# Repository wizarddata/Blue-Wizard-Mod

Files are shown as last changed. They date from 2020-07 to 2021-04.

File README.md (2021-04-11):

# Blue Wizard Mod

This is an open source bluetooth controller for the Kinesis Advantage and Advantage 2 (see below) line of keyboards using the BlueMicro firmware.

Firmware can be found here. https://github.com/wizarddata/BlueMicro_BLE/tree/blue-wizard-working

For now, use the fork linked above to make any layout changes and utilize the adafruit nrf52832 BSP.

Gerbers and BOM are available if you'd like to build your own! If you're interested in purchasing an assembled mod email me at andrew.wells88@gmail.com or check out my etsy store. If you're so inclined, I can install a mod in your keyboard as well.
 
 https://www.etsy.com/shop/WizardKeyboards?ele=shop_open
 
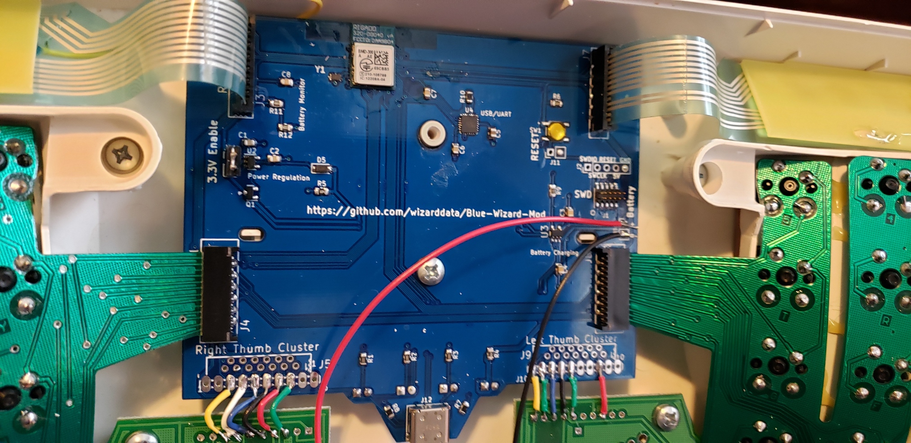
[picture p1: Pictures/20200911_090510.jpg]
Image_of_Rev0


You will need some additional hardware to make your board functional. Links are provided below for guidance:

1) Latching/Toggle/Rocker panel mount switch for power, or bridge J14 pins for always on. 

 https://www.sparkfun.com/products/11138

2) USB-C panel mount extension.
 
 https://www.amazon.com/dp/B08169ZB5C/ref=cm_sw_r_cp_api_glt_fabc_G1MT1V5PB9B76P2SWG2N?_encoding=UTF8&psc=1
 https://www.sparkfun.com/products/15455  
 
3) Momentary panel mount switch for reset (optional, reset switch is onboard).

 https://www.sparkfun.com/products/11995

4) LiPo battery.

 https://www.sparkfun.com/products/13855

***Advantage 2 Troubleshooting***  
Some keyboards experience intermittent joined activations on function keys. Installing a jumper wire from the negative battery connection to the ground pin of the 3.3v regulator can help resolve this issue. The necessary wire is pictured here:  
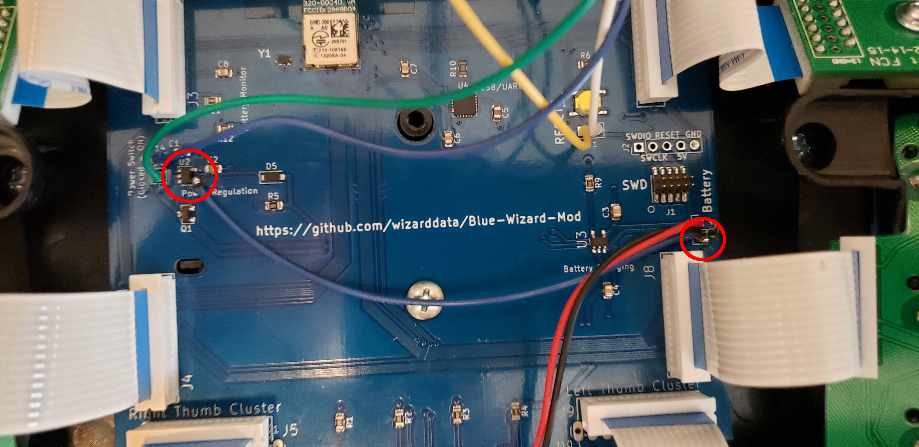
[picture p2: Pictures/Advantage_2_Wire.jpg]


Some users have reported F1 simultateously triggering F2. A 10k resistor between the pins indicated here will resolve this.  
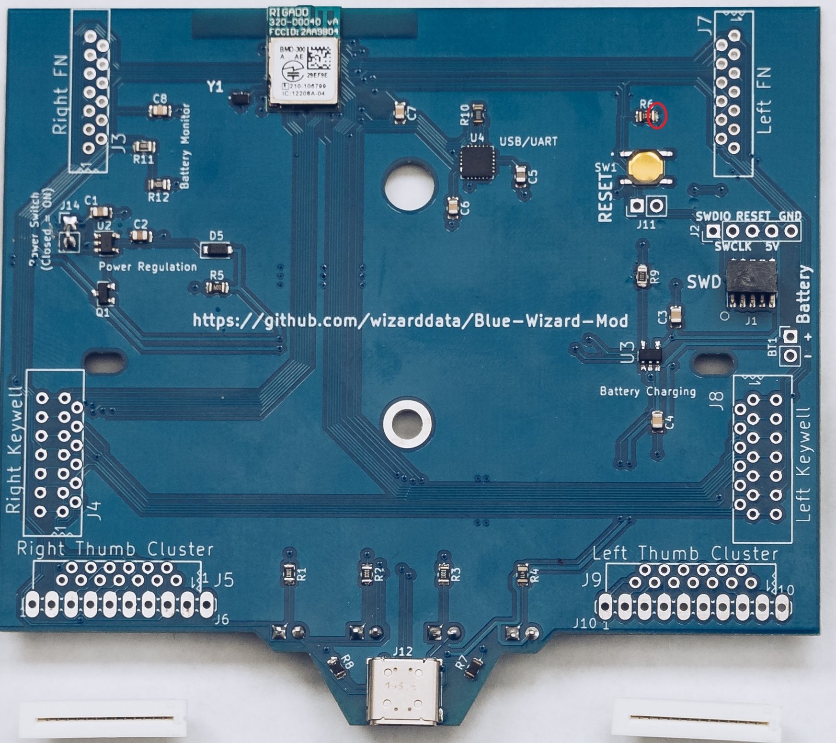
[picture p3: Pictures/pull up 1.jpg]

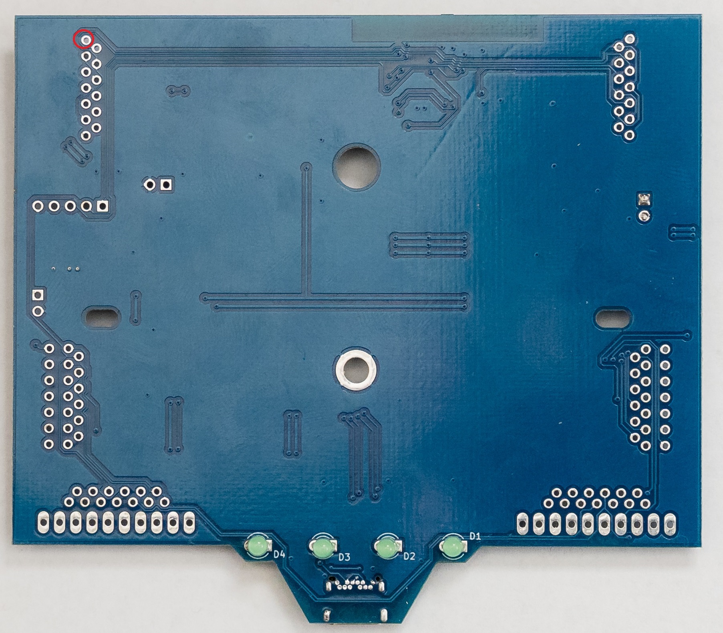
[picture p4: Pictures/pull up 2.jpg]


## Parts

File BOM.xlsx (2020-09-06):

 | Mfr. # | Description | Order Qty.
C5 | C0805C106K9PACTU | Multilayer Ceramic Capacitors MLCC - SMD/SMT 6.3volts 10uF X5R 10% | 1
C6, C7 | 885012207098 | Multilayer Ceramic Capacitors MLCC - SMD/SMT WCAP-CSGP 0.1uF 0805 10% 50V MLCC | 2
C8 | 885342207008 | Multilayer Ceramic Capacitors MLCC - SMD/SMT WCAP-CSMH 250V 1000pF 0805 10% | 1
R1, R2, R3 | CRCW08051K00FKEAC | Thick Film Resistors - SMD 1/8Watt 1Kohms 1% Commercial Use | 3
R9 | CR0805-FX-2101ELF | Thick Film Resistors - SMD 2.1K 1% | 1
R11 | CR0805-FX-8063ELF | Thick Film Resistors - SMD 806K 1% | 1
R12 | WCR0805LF2004FPLT | Thick Film Resistors - SMD 2M OHM 1% | 1
U4 | CP2104-F03-GM | I/O Controller Interface IC USB to UART Bridge QFN24 | 1
Y1 | SiT1533AI-H4-DCC-32.768E | Standard Clock Oscillators 32.768KHz R2R LVCMOS -40 to 85C 100ppm | 1
R10 | CRCW0805100RFKEA | Thick Film Resistors - SMD 1/8watt 100ohms 1% 100ppm | 1
C3, C4 | 0805X475M250CT | Multilayer Ceramic Capacitors MLCC - SMD/SMT 0805 MLCC X5R 4.7 uF +/- 20% 25 V T&R GP | 2
D5 | MBR120ESFT3G | Schottky Diodes & Rectifiers 1A 20V | 1
Q1 | BSS84 | MOSFET SOT-23 P-CH ENHANCE | 1
C1, C2 | 885012207078 | Multilayer Ceramic Capacitors MLCC - SMD/SMT WCAP-CSGP 1uF 0805 10% 25V MLCC | 2
R6 | CRCW080510K0FKEAC | Thick Film Resistors - SMD 1/8Watt 10Kohms 1% Commercial Use | 1
R5 | CRCW0805100KJNEAC | Thick Film Resistors - SMD 1/8Watt 100Kohms 5% Commercial Use | 1
R7, R8 | CRCW08055K10FKEA | Thick Film Resistors - SMD 1/8watt 5.1Kohms 1% 100ppm | 2
D1-D4 | LTL-4231N | Standard LEDs - Through Hole Green Diffused | 4
J12 | 10137062-00021LF | USB Connectors USB 3.1 RECE. CONN. Gen 1 | 1
SW1 | PTS526 SM08 SMTR2 LFS | Tactile Switches 50mA 12VDC, 5.2x5.2mm, 0.8mm H, 160gf, G leads, No ground pin, no actuator | 1
J1 | 20021121-00010C4LF | Headers & Wire Housings 1.27x1.27mm BTB, Hdr Unshrd, SMT, 10 Pos | 1
U3 | MCP73831T-2ACI/OT | Battery Management Charge mgnt contr | 1
U1 | BMD-300-A-R | Bluetooth Modules (802.15.1) Bluetooth Module Low Energy 5.0 | 1
R4 | RK73B2ATTD471J | Thick Film Resistors - SMD 1/4watts 470ohms 5% | 1
U2 | MIC5504-3.3YM5-TR | LDO Voltage Regulators Single 300mA LDO | 1
J4, J8 | 39-53-2134 | Right Angle FFC/FPC 13 POS Through Hole | 0-2 | These connectors vary depending on your advantage model.
J3, J4, J5, J7, J8, J9 | 39-53-2135 | Vertical FFC/FPC 13 POS Through Hole | 2-6

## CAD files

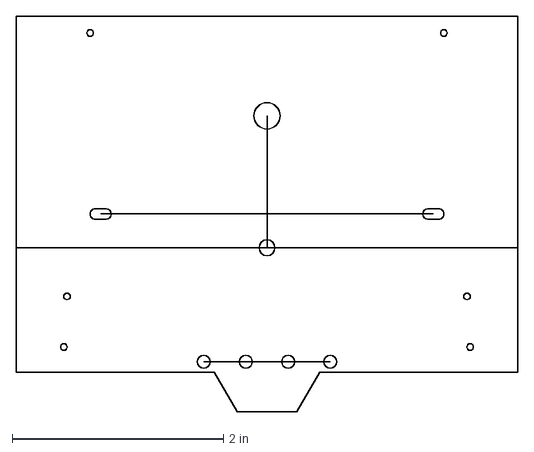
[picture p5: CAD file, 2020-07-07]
Blue Wizard PCB Footprint.dxf
4.75 x 3.75 in

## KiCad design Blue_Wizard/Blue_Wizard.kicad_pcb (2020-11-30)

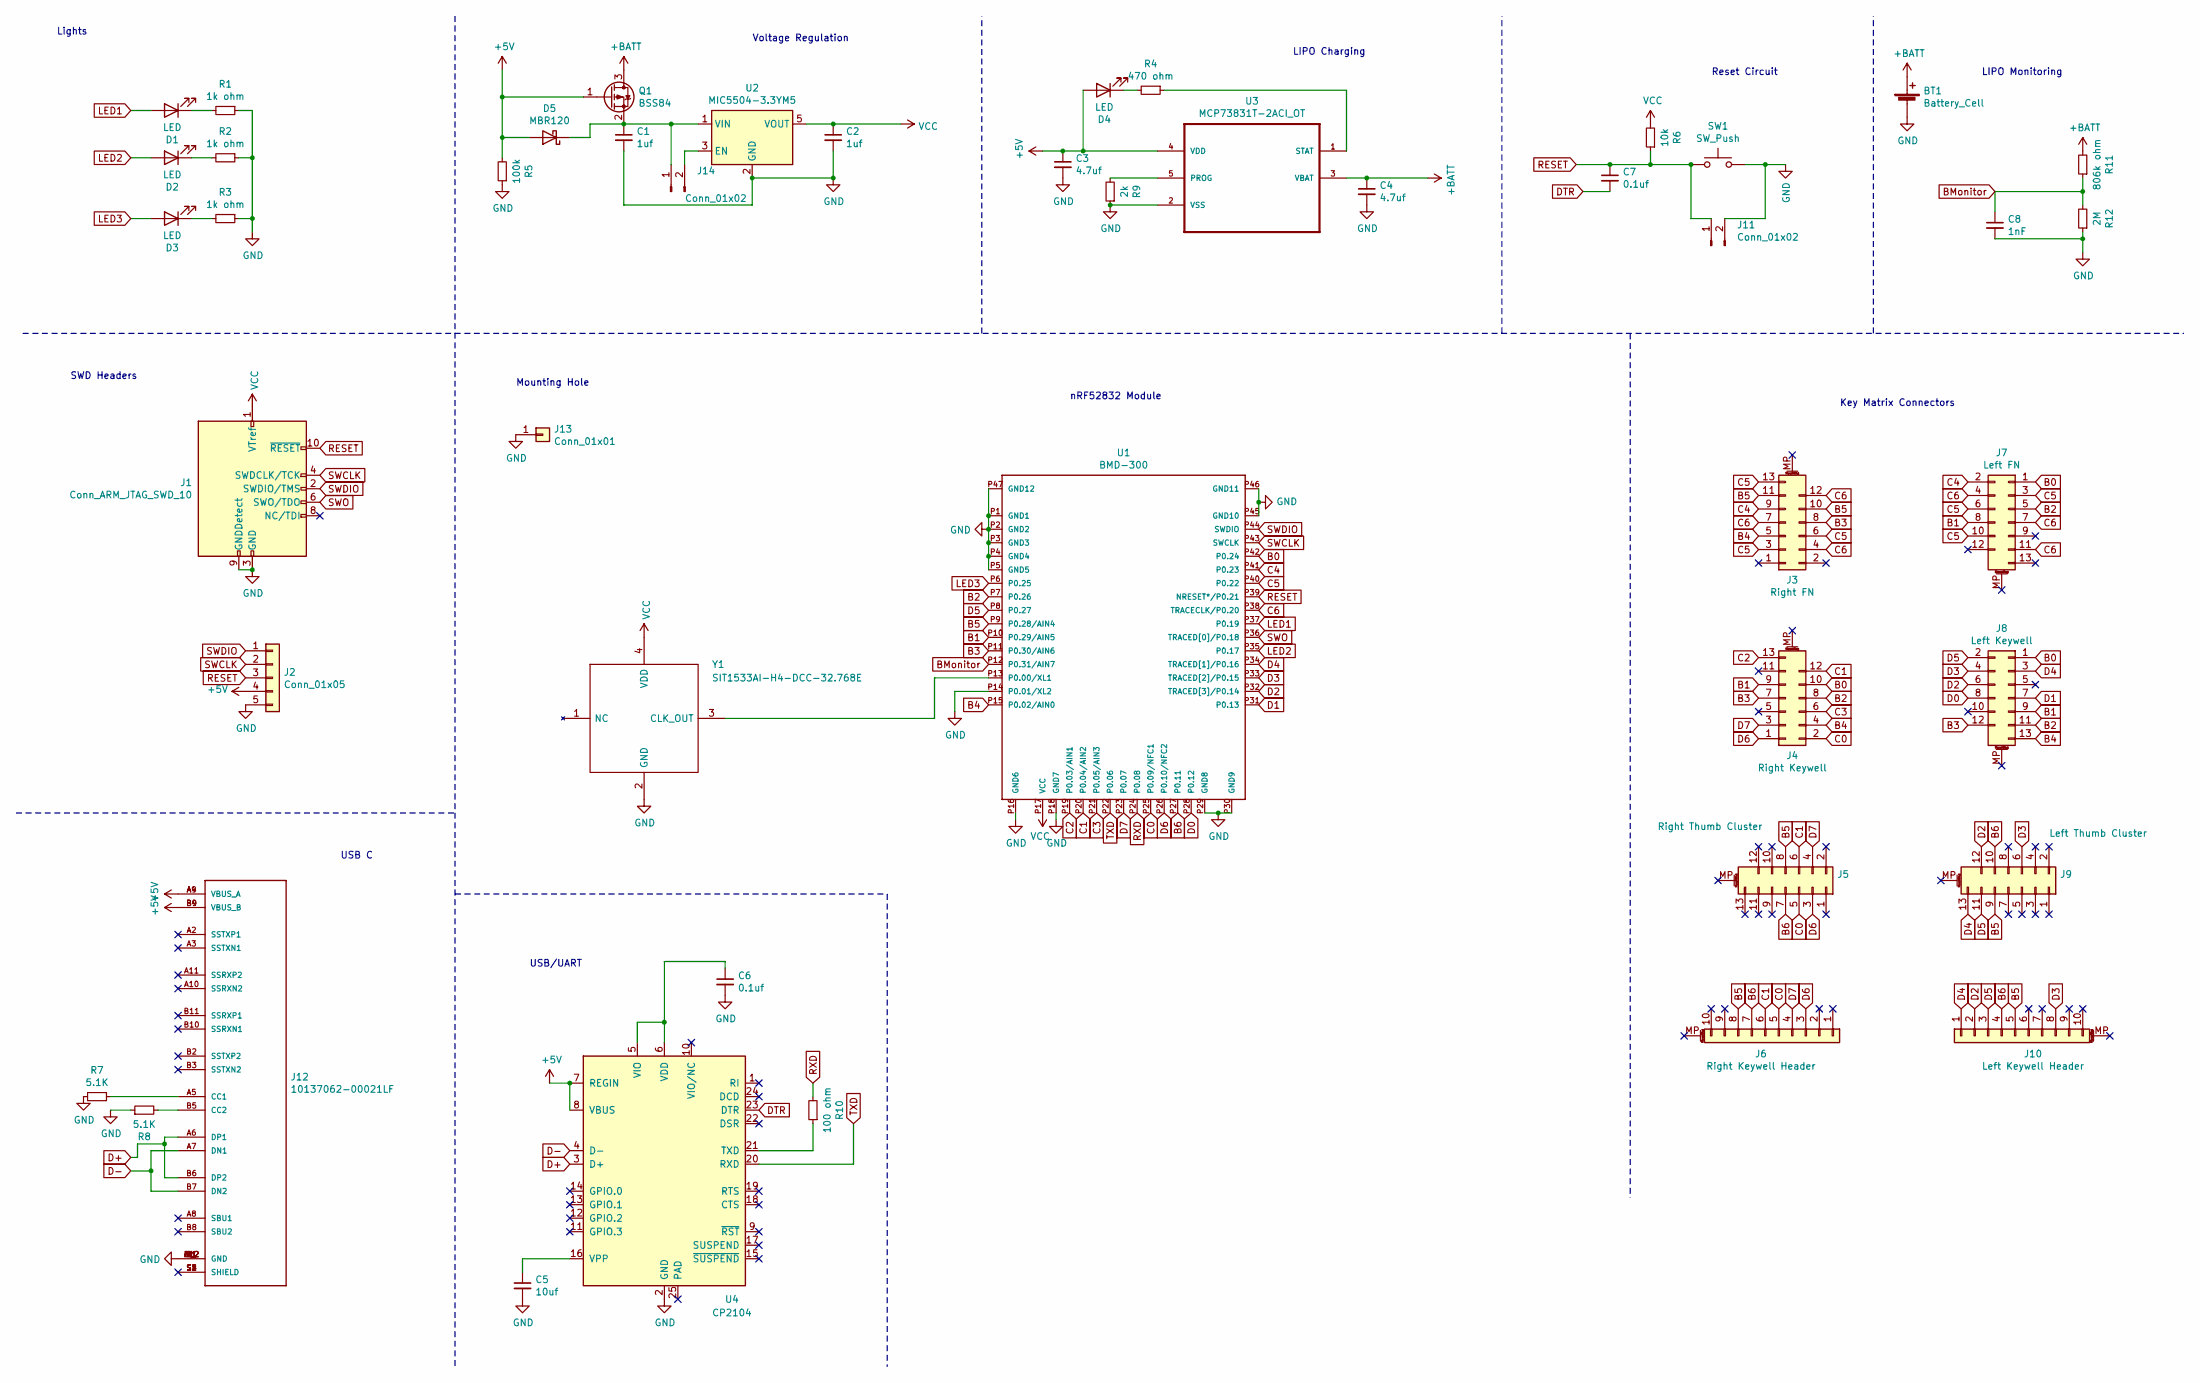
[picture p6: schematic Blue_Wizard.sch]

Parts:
BT1: Battery_Cell; PinHeader_1x02_P2.54mm_Vertical
C1, C2: 1uf; C_0805_2012Metric
C3, C4: 4.7uf; C_0805_2012Metric
C5: 10uf; C_0805_2012Metric
C6, C7: 0.1uf; C_0805_2012Metric
C8: 1nF; C_0805_2012Metric
D1, D2, D3, D4: LED; LED_D3.0mm_Clear
D5: MBR120; D_SOD-123F
J1: Conn_ARM_JTAG_SWD_10; PinHeader_2x05_P1.27mm_Vertical_SMD
J2: Conn_01x05; PinHeader_1x05_P2.54mm_Vertical
J3: Right FN; Vertical_FRC
J4: Right Keywell; Horizontal_FRC
J5: Right Thumb Cluster; Vertical_FRC
J6: Right Keywell Header; MA10-1
J7: Left FN; Vertical_FRC
J8: Left Keywell; Horizontal_FRC
J9: Left Thumb Cluster; Vertical_FRC
J10: Left Keywell Header; MA10-1
J11, J14: Conn_01x02; PinHeader_1x02_P2.54mm_Vertical
J12: 10137062-00021LF; CONN_10137062-00021LF
J13: Conn_01x01; Mounting Hole
Q1: BSS84; SOT-23
R1, R2, R3: 1k ohm; R_0805_2012Metric
R4: 470 ohm; R_0805_2012Metric
R5: 100k; R_0805_2012Metric
R6: 10k; R_0805_2012Metric
R7, R8: 5.1K; R_0805_2012Metric
R9: 2k; R_0805_2012Metric
R10: 100 ohm; R_0805_2012Metric
R11: 806k ohm; R_0805_2012Metric
R12: 2M; R_0805_2012Metric
SW1: SW_Push; SW_PTS526_SM08_SMTR2_LFS
U1: BMD-300
U2: MIC5504-3.3YM5; SOT-23-5
U3: MCP73831T-2ACI_OT; SOT95P280X145-5N
U4: CP2104; QFN-24-1EP_4x4mm_P0.5mm_EP2.6x2.6mm
Y1: SIT1533AI-H4-DCC-32.768E; SIT1533AIH4DCC32768E; Mouser Part Number 788-1533AIH4DCC32.76

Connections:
+5V: C3.1, D4.2 (A), D5.2 (A), J2.4, J12.A4 (VBUS_A), J12.A9 (VBUS_A), J12.B4 (VBUS_B), J12.B9 (VBUS_B), Q1.1 (G), R5.2, U3.4 (VDD), U4.7 (REGIN), U4.8 (VBUS)
+BATT: BT1.1 (+), C4.1, Q1.3 (D), R11.2, U3.3 (VBAT)
B0: J4.10, J7.1, J8.1, U1.P42 (P0.24)
B1: J4.9, J7.8, J8.9, U1.P10 (P0.29/AIN5)
B2: J4.8, J7.5, J8.11, U1.P7 (P0.26)
B3: J3.8, J4.7, J8.12, U1.P11 (P0.30/AIN6)
B4: J3.5, J4.4, J8.13, U1.P15 (P0.02/AIN0)
B5: J3.10, J3.11, J5.8, J6.8, J9.9, J10.5, U1.P9 (P0.28/AIN4)
B6: J5.7, J6.7, J9.10, J10.4, U1.P27 (P0.11)
BMonitor: C8.1, R11.1, R12.2, U1.P12 (P0.31/AIN7)
C0: J4.2, J5.5, J6.5, U1.P25 (P0.09/NFC1)
C1: J4.12, J5.6, J6.6, U1.P20 (P0.04/AIN2)
C2: J4.13, U1.P19 (P0.03/AIN1)
C3: J4.6, U1.P21 (P0.05/AIN3)
C4: J3.9, J7.2, U1.P41 (P0.23)
C5: J3.3, J3.6, J3.13, J7.3, J7.6, J7.10, U1.P40 (P0.22)
C6: J3.4, J3.7, J3.12, J7.4, J7.7, J7.11, U1.P38 (TRACECLK/P0.20)
D0: J8.8, U1.P28 (P0.12)
D1: J8.7, U1.P31 (P0.13)
D2: J8.6, J9.12, J10.2, U1.P32 (TRACED[3]/P0.14)
D3: J8.4, J9.6, J10.8, U1.P33 (TRACED[2]/P0.15)
D4: J8.3, J9.13, J10.1, U1.P34 (TRACED[1]/P0.16)
D5: J8.2, J9.11, J10.3, U1.P8 (P0.27)
D6: J4.1, J5.3, J6.3, U1.P26 (P0.10/NFC2)
D7: J4.3, J5.4, J6.4, U1.P23 (P0.07)
D+: J12.A6 (DP1), J12.B6 (DP2), U4.3 (D+)
D-: J12.A7 (DN1), J12.B7 (DN2), U4.4 (D-)
DTR: C7.2, U4.23 (DTR)
GND: BT1.2 (-), C1.2, C2.2, C3.2, C4.2, C5.2, C6.2, C8.2, J1.3 (GND), J1.5 (GND), J1.9 (GNDDetect), J2.5, J11.2, J12.A1 (GND), J12.A12 (GND), J12.B1 (GND), J12.B12 (GND), J13.1, R1.1, R2.1, R3.1, R5.1, R7.2, R8.1, R9.1, R12.1, SW1.2, U1.P1 (GND1), U1.P2 (GND2), U1.P3 (GND3), U1.P4 (GND4), U1.P5 (GND5), U1.P14 (P0.01/XL2), U1.P16 (GND6), U1.P18 (GND7), U1.P29 (GND8), U1.P30 (GND9), U1.P45 (GND10), U1.P46 (GND11), U1.P47 (GND12), U2.2 (GND), U3.2 (VSS), U4.2 (GND), Y1.2 (GND)
LED1: D1.2 (A), U1.P37 (P0.19)
LED2: D2.2 (A), U1.P35 (P0.17)
LED3: D3.2 (A), U1.P6 (P0.25)
unnamed: C1.1, D5.1 (K), J14.1, Q1.2 (S), U2.1 (VIN)
unnamed: C5.1, U4.16 (VPP)
unnamed: C6.1, U4.5 (VIO), U4.6 (VDD)
unnamed: D1.1 (K), R1.2
unnamed: D2.1 (K), R2.2
unnamed: D3.1 (K), R3.2
unnamed: D4.1 (K), R4.2
unnamed: J12.A5 (CC1), R7.1
unnamed: J12.B5 (CC2), R8.2
unnamed: J12.S1 (SHIELD), J12.S2 (SHIELD), J12.S3 (SHIELD), J12.S4 (SHIELD)
unnamed: J14.2, U2.3 (EN)
unnamed: R4.1, U3.1 (STAT)
unnamed: R9.2, U3.5 (PROG)
unnamed: R10.1, U4.21 (TXD)
unnamed: U1.P13 (P0.00/XL1), Y1.3 (CLK_OUT)
RESET: C7.1, J1.10 (~RESET~), J2.3, J11.1, R6.1, SW1.1, U1.P39 (NRESET*/P0.21)
RXD: R10.2, U1.P24 (P0.08)
SWCLK: J1.4 (SWDCLK/TCK), J2.2, U1.P43 (SWCLK)
SWDIO: J1.2 (SWDIO/TMS), J2.1, U1.P44 (SWDIO)
SWO: J1.6 (SWO/TDO), U1.P36 (TRACED[0]/P0.18)
TXD: U1.P22 (P0.06), U4.20 (RXD)
VCC: C2.1, J1.1 (VTref), R6.2, U1.P17 (VCC), U2.5 (VOUT), Y1.4 (VDD)

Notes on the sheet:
SWD Headers
Lights
Voltage Regulation
LIPO Charging
Reset Circuit
LIPO Monitoring
Key Matrix Connectors
Mounting Hole
USB/UART
USB C
nRF52832 Module

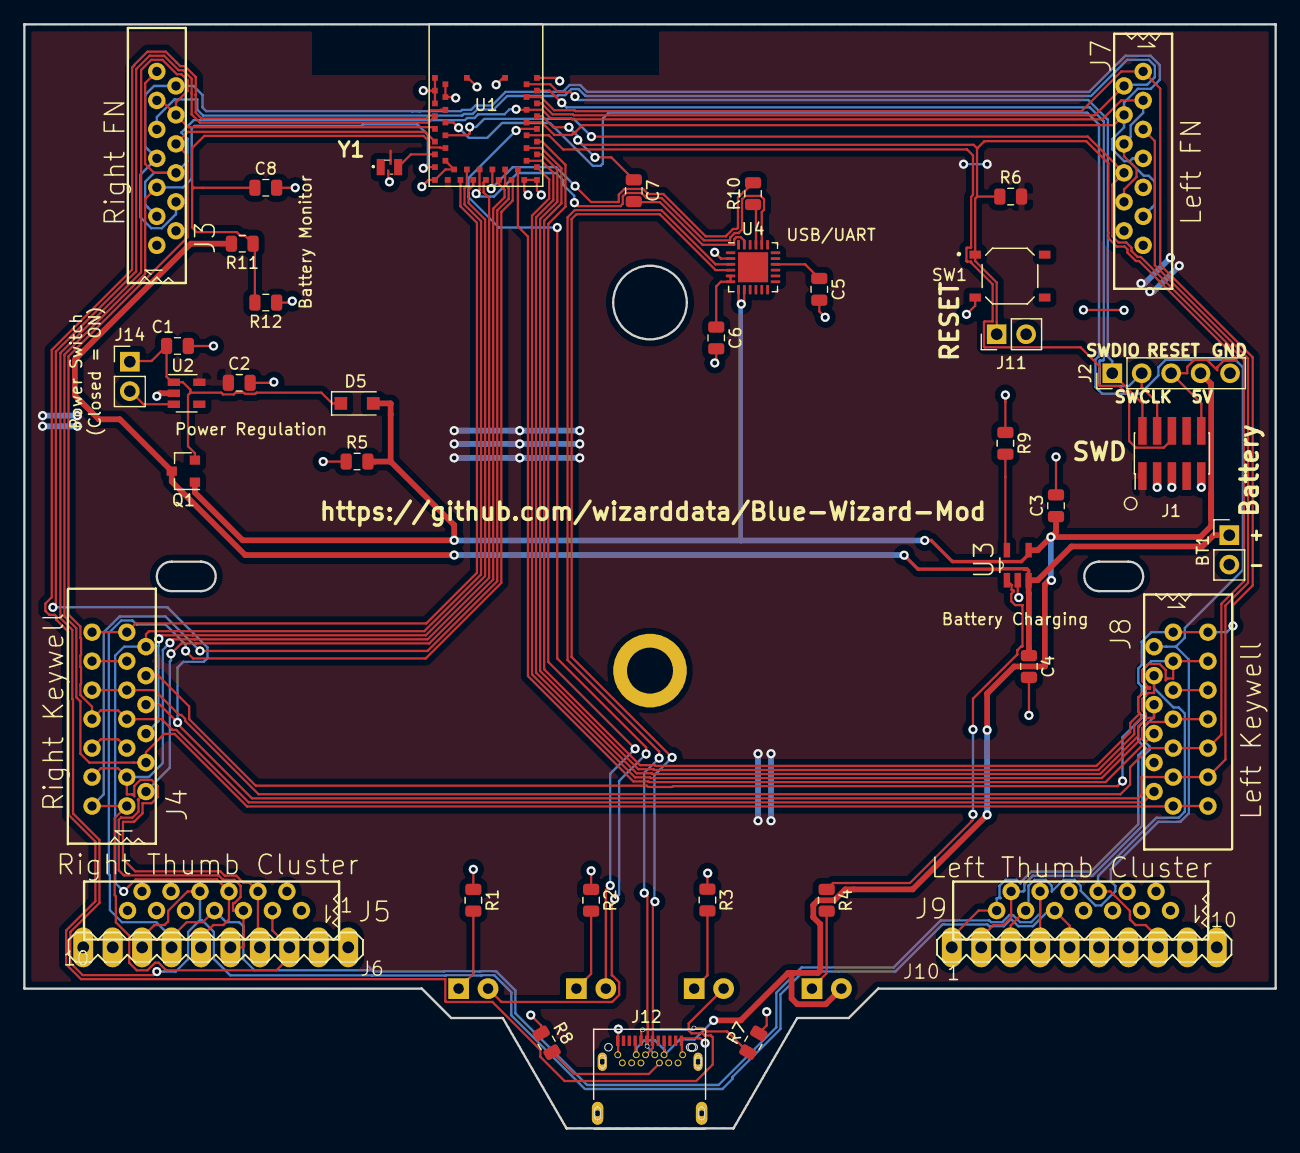
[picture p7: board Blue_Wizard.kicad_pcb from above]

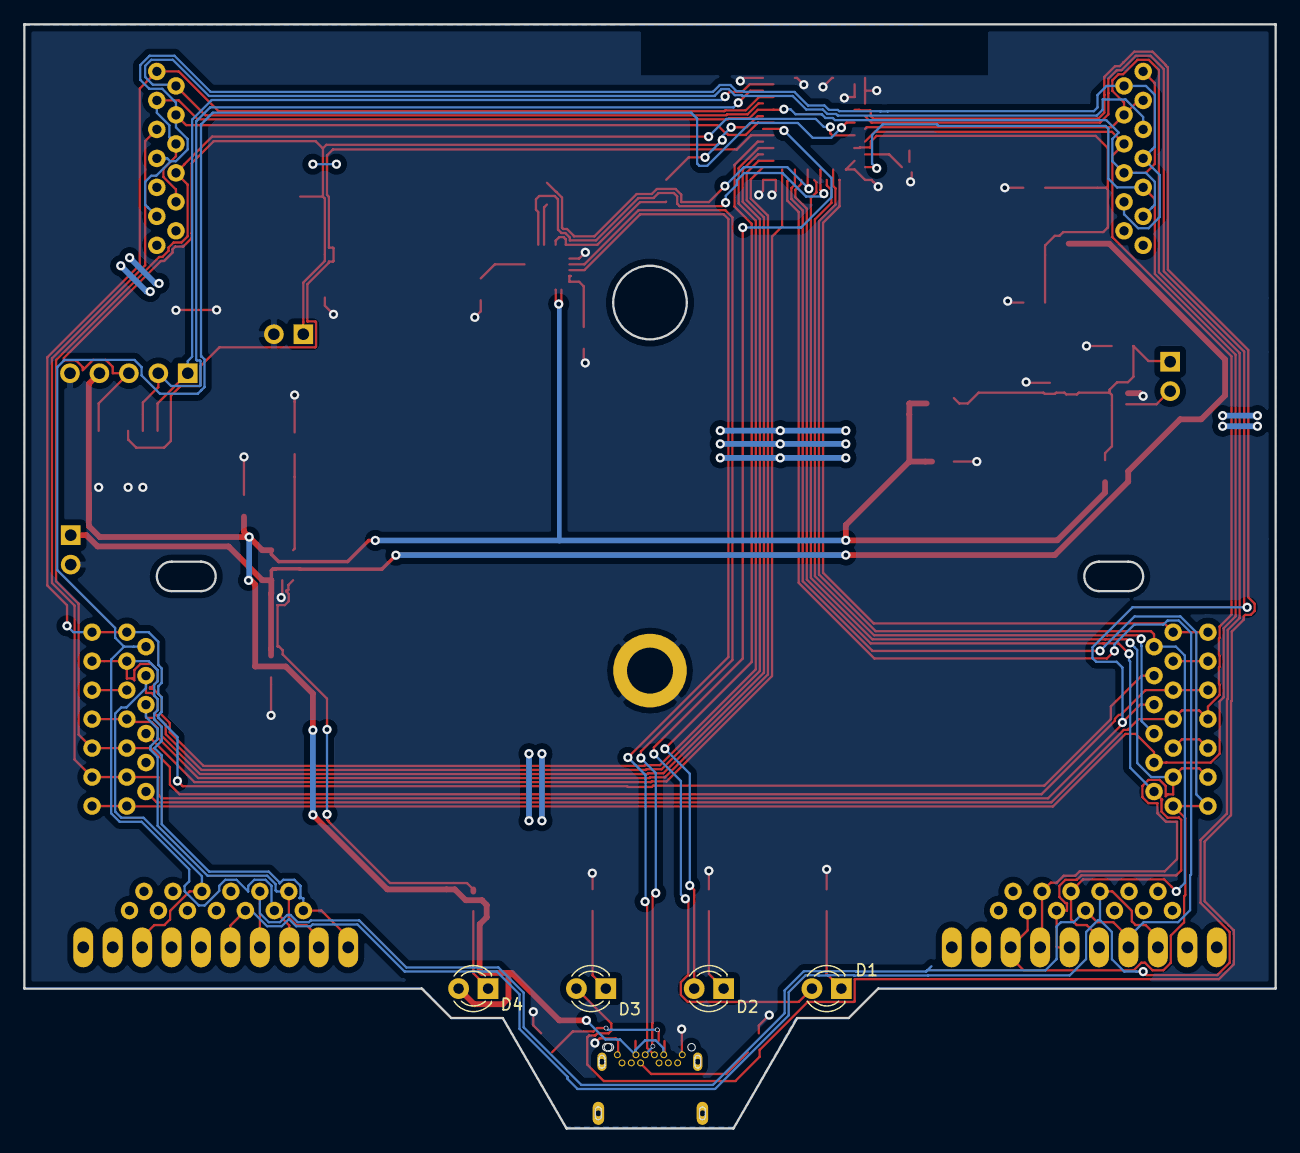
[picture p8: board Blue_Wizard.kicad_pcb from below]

Board: 2 copper layers, 108.0 x 95.2 mm, 47 parts (4 on the bottom side), 54 nets.

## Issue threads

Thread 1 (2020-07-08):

qmk ?

lazy-unicorn, 2020-07-08:
sup fellow kinesis user -

is there a good reason why you make your life harder then necessary ?

nordic is cool and all but there are easyer ways out of that hell

uart/spi integration works with like any arm mcu or even smaller/cheaper ones
https://beta.docs.qmk.fm/using-qmk/hardware-features/feature_bluetooth
if you design your power logic / regular mcu ( say STM32F303 ) - all it takes to make the board bt capeable is to connect the bt modul via spi/uart to the main mcu and "bob is your uncle" you even find some example firmware with bt in qmk repo

or

https://github.com/sysdevmike/KinesisBLE - works with your nordic soc

wizarddata, 2020-07-08:
Sup dawg.

I spent some time with the QMK implementation of bluetooth a while back, worked jut fine but the battery life was much shorter than I would like (on the order of 5 days on a ~2000mah 18650).

I went with BlueMicro because it is a more widely used bluetooth firmware than the kinesis specific KinesisBLE project. My thought was it would lead to more features down the road as development continued. Even with the KinesisBLE project, it would require an Adafruit feather module and an MCP23S17 I/O expander without the same porting I'm doing here. That is, unless I'm missing something, which is entirely possible.

lazy-unicorn, 2020-07-10:
valid - did not think about that - battery may be extendable if reducing the scanning rate / frequency of the chip

if we talk about features qmk is the clear winner here
+ more features also require more mcu cycles = more power drain.

i have a look in the firmware you got already and see what i can do

wizarddata, 2020-07-10:
I'd definitely appreciate the help. Where I'm at is (thanks to a lot of help from the adafruit forum and bluemicro discord) I've got a new bootloader to fix the LED pins, a customized BSP to account for my not including a LF oscillator, and a procedure to correct for some work that is usually done by adafruit-nrfutil when programmed over serial. The test code BlueMicroHID_tester works perfectly but the firmware I'm building for my board stops advertising after 1-2 seconds.

wizarddata, 2020-07-15:
Got the booting issues sorted and even got to the point where I could use all the IO I needed, then ran out of dynamic memory. This project is going to get upgraded to a 840.

Closed 2020-07-15.

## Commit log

2020-07-25 Update README.md
    Updated to reflect functioning prototype.
2020-08-07 Rev 0 in progress
    [BOM.xlsx, Blue_Wizard.kicad_pcb, Blue_Wizard.sch]
2020-08-15 Generated Rev 0 gerbers
    [Blue_Wizard-B_Cu.gbr, Blue_Wizard-B_Mask.gbr, Blue_Wizard-B_SilkS.gbr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]
2020-08-25 readme update
    [Blue_Wizard.kicad_pcb, Blue_Wizard.sch]
2020-09-06 Final Gerbers and BOM
    [BOM.xlsx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]
2020-09-11 Rev 0a board complete
    [Blue_Wizard-B_Cu.gbr, Blue_Wizard-B_Mask.gbr, Blue_Wizard-B_SilkS.gbr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]
2020-11-30 Updated front silkscreen and removed KiCad project
    [Blue_Wizard-B_Cu.gbr, Blue_Wizard-B_Mask.gbr, Blue_Wizard-B_SilkS.gbr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]
2020-11-30 Cleaned up KiCad project
    [Blue_Wizard-B_Cu.gbr, Blue_Wizard-B_Mask.gbr, Blue_Wizard-B_SilkS.gbr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]
